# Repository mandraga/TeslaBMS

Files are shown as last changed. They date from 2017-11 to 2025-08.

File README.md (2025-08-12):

## Adaptation to Teensy 4.

This fork branches to adapt to the Teensy 4, it needs an interface board pcb or a carrier board redesign.
See the VW BMS fork or the pull request at the original repo for adapter PCB in Kicad format.

# TeslaBMS

Based off work done by Collin Kidder

Designed to work with my own board design and a Teensy 3.2

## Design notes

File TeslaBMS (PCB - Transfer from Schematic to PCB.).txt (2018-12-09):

Transfer from Schematic to PCB.
-------------------------------

Report Written:     Wednesday, April 18, 2018
Design Path:        C:\Users\tomde\Documents\GitHub\TeslaBMS\TeslaBMS.pcb
Design Title:       
Created:            18-Apr-18 9:27:16 PM
Last Saved:         18-Apr-18 9:27:25 PM
Editing Time:       0 min
Units:              thou (precision 0)

Net class "default" was not defined, but has been created. Please check the values in the PCB design.
Could not load component "R-78XX" package "R-78XX" into target design.
Could not add "U1" component "R-78XX" package "R-78XX" to target design.
Could not load component "MCP2510-I/SO" package "SOIC127P1034X264-18N" into target design.
Could not add "U$2" component "MCP2510-I/SO" package "SOIC127P1034X264-18N" to target design.
Could not load component "PCA82C250T/N4,112" package "SOIC127P600X175-8N" into target design.
Could not add "U2" component "PCA82C250T/N4,112" package "SOIC127P600X175-8N" to target design.
Could not load component "CRYSTALSM49" package "SM49" into target design.
Could not add "Q1" component "CRYSTALSM49" package "SM49" to target design.
PCB component "R1" does not have a pad numbered .
Could not load component "BTS5440G" package "PG-DSO-28" into target design.
Could not add "IC2" component "BTS5440G" package "PG-DSO-28" to target design.
Could not load component "22-27-2041-04" package "6410-04" into target design.
Could not add "J2" component "22-27-2041-04" package "6410-04" to target design.
Could not add "J3" component "22-27-2041-04" package "6410-04" to target design.
PCB component "C11" does not have a pad numbered .
PCB component "C14" does not have a pad numbered .
PCB component "C17" does not have a pad numbered .
PCB component "R4" does not have a pad numbered .
Could not load component "FDD4141TO252" package "TO252" into target design.
Could not add "Q3" component "FDD4141TO252" package "TO252" to target design.
Could not load component "NPN-TRANSISTOR_SOT23" package "SOT23" into target design.
Could not add "Q4" component "NPN-TRANSISTOR_SOT23" package "SOT23" to target design.
Could not load component "TEENSY_3.1_DIL" package "TEENSY3-DIL" into target design.
Could not add "U$4" component "TEENSY_3.1_DIL" package "TEENSY3-DIL" to target design.
PCB component "R6" does not have a pad numbered .
Could not load component "ILD205" package "SOIC08" into target design.
Could not add "OK2" component "ILD205" package "SOIC08" to target design.
PCB component "R5" does not have a pad numbered .
PCB component "R7" does not have a pad numbered .
PCB component "R8" does not have a pad numbered .
PCB component "R9" does not have a pad numbered .
Could not load component "5566-8" package "5566-8" into target design.
Could not add "X1" component "5566-8" package "5566-8" to target design.
PCB component "R2" does not have a pad numbered .
PCB component "R3" does not have a pad numbered .
PCB component "R10" does not have a pad numbered .
PCB component "R11" does not have a pad numbered .
PCB component "R12" does not have a pad numbered .
PCB component "R13" does not have a pad numbered .
Could not load component "MOSFET-NGDS_TO220V" package "TO220V" into target design.
Could not add "Q2" component "MOSFET-NGDS_TO220V" package "TO220V" to target design.
Could not add "Q5" component "MOSFET-NGDS_TO220V" package "TO220V" to target design.

End Of Report.

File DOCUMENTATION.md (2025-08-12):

Install the autowp MCP2515 library from the library menu.

Install the ADC library from https://github.com/pedvide/ADC from a zip file.

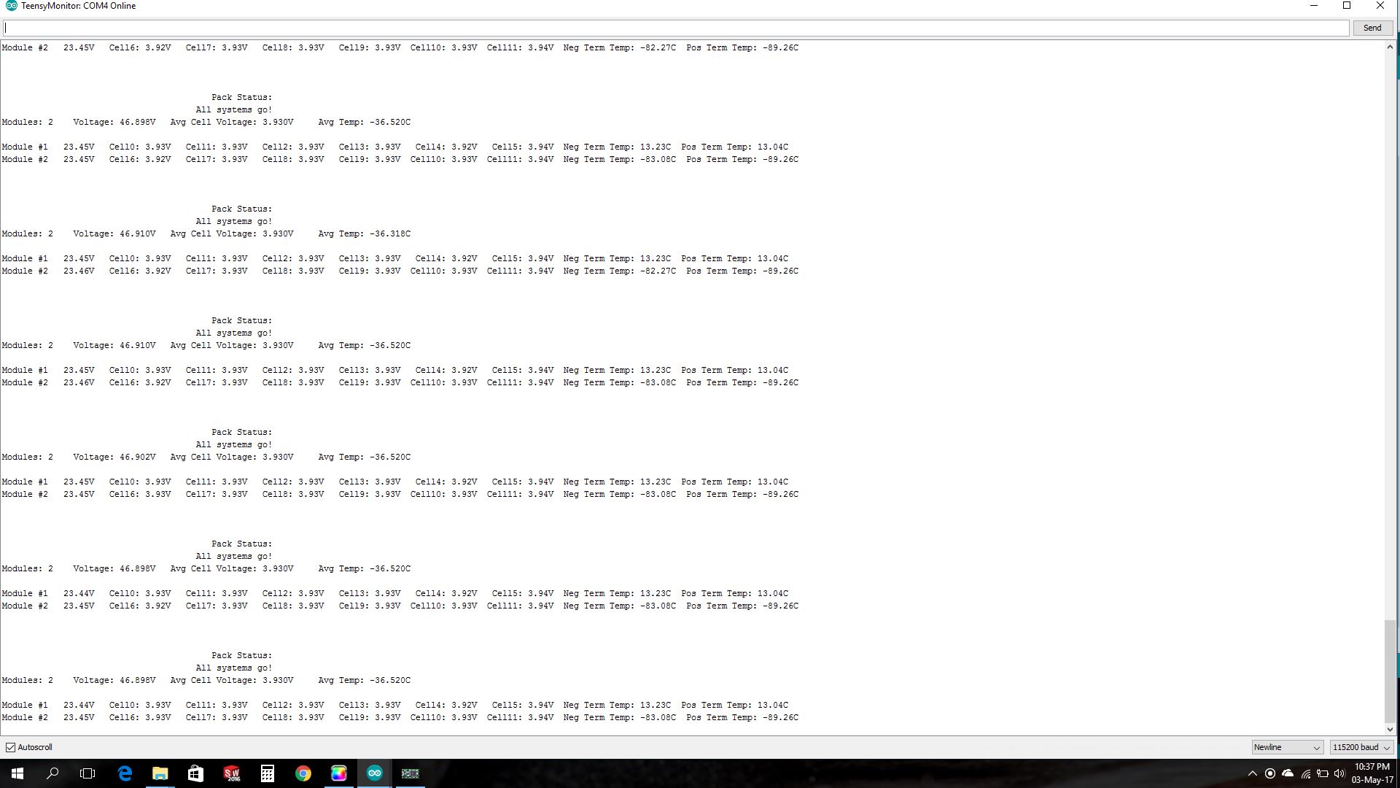
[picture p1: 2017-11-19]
running.JPG

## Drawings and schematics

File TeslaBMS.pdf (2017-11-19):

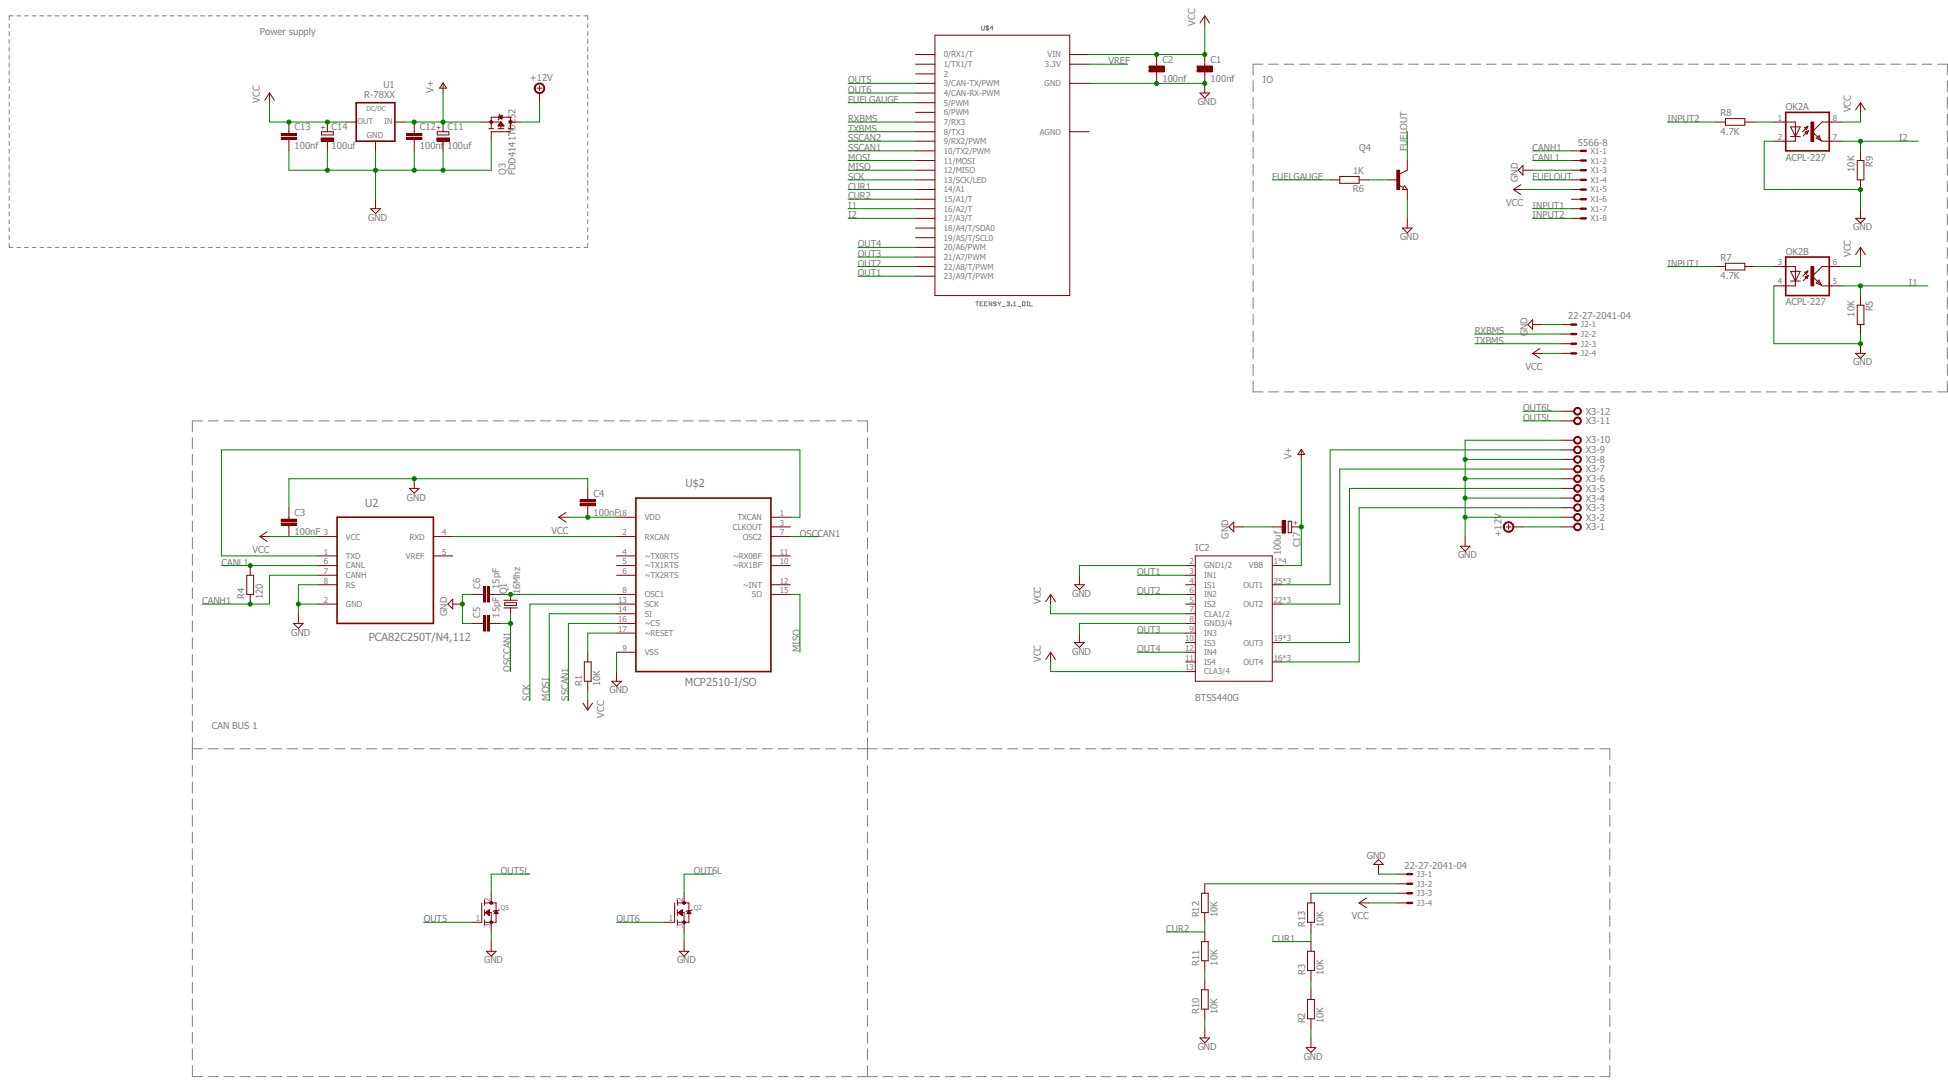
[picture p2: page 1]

~RESET 17

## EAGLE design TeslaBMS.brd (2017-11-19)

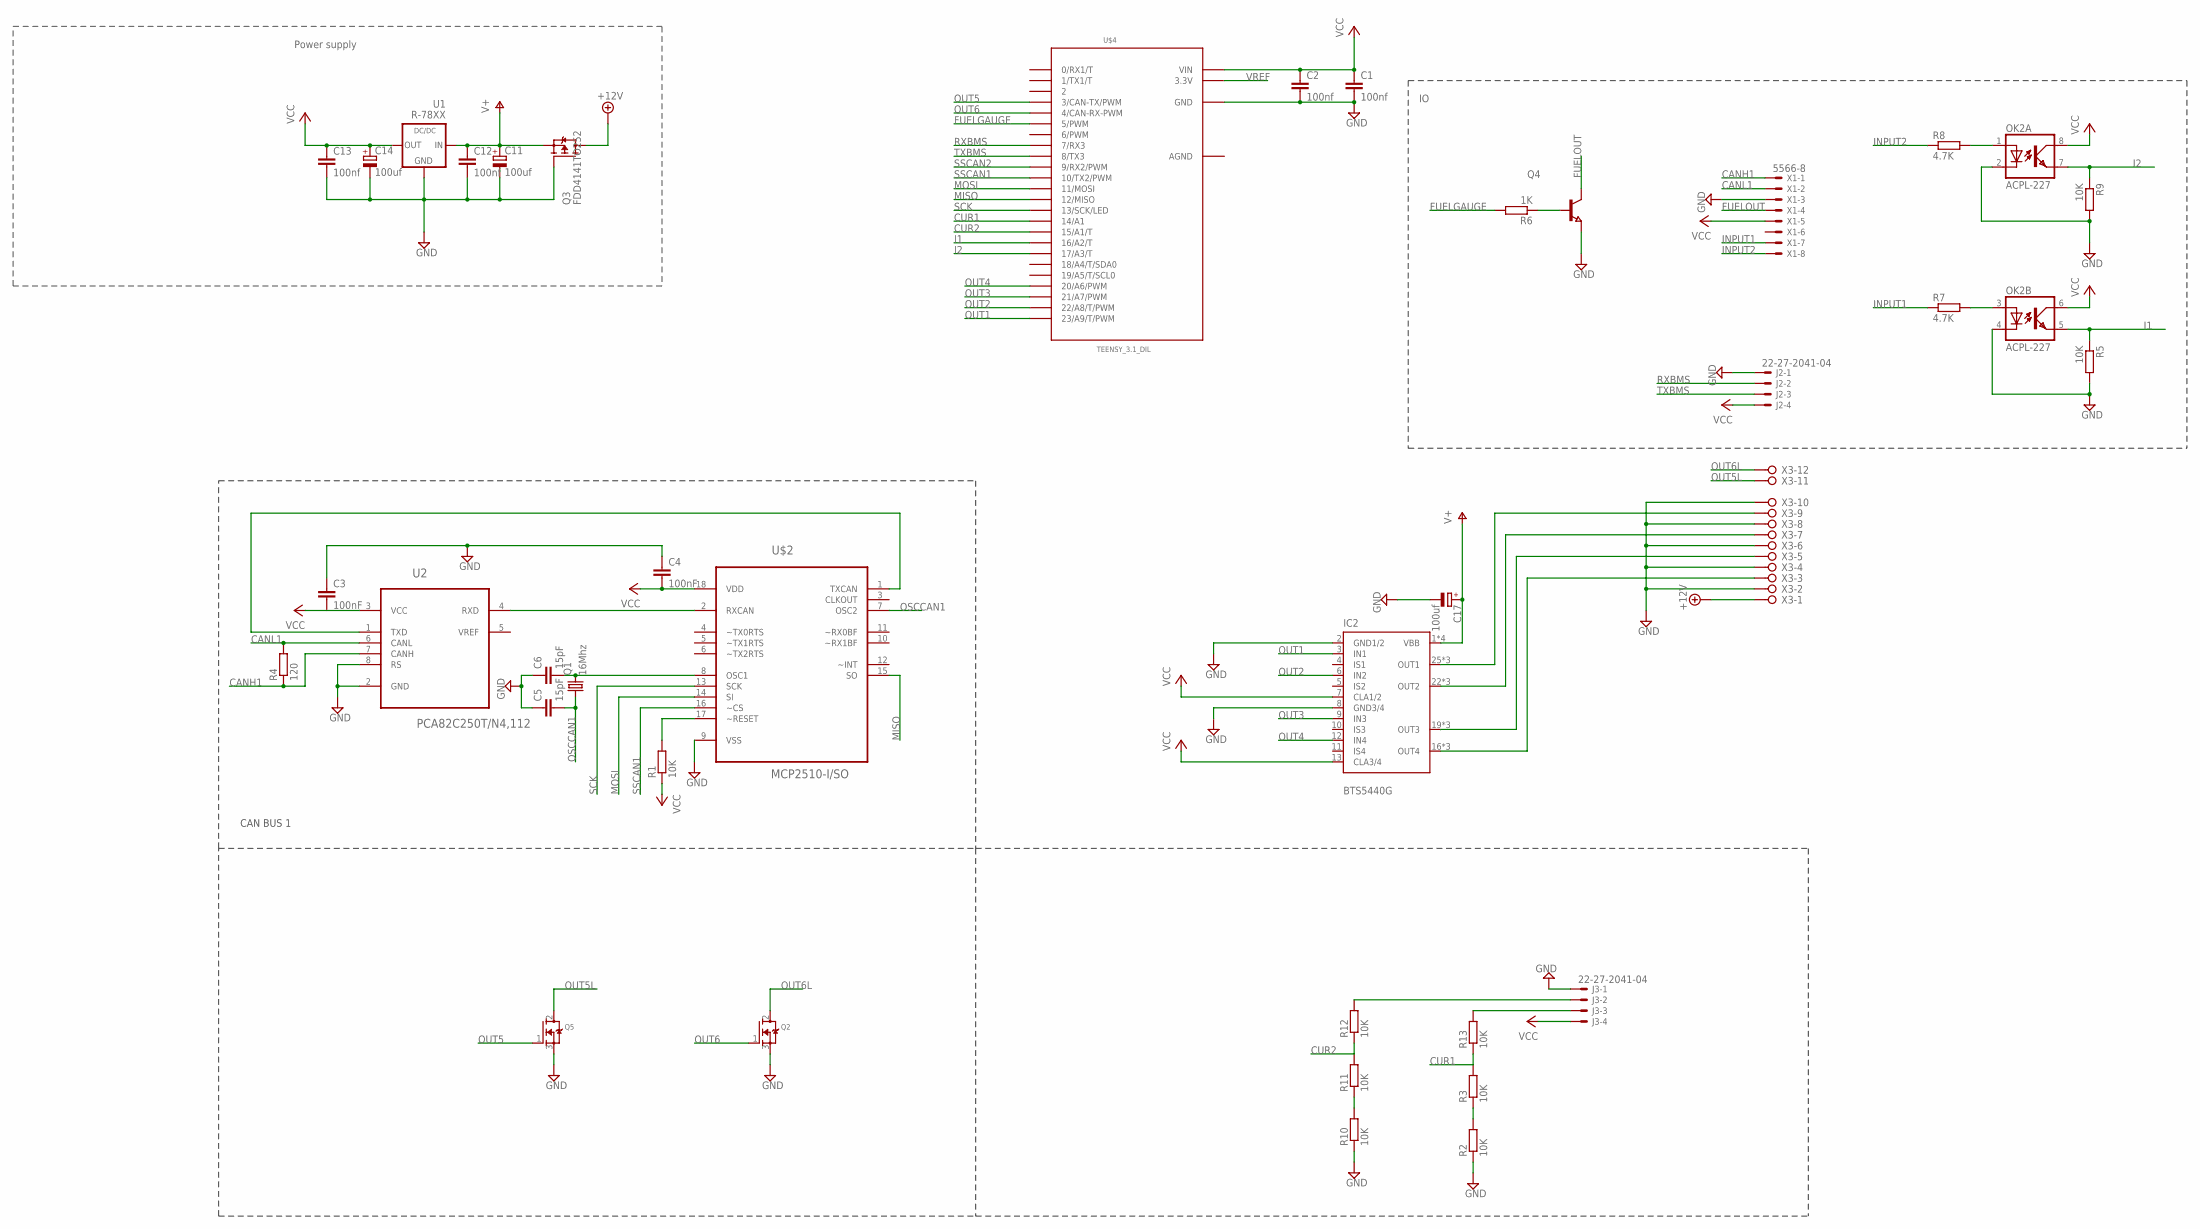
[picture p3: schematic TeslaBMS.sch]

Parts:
C1, C2, C12, C13: 100nf; C0805
C3, C4: 100nF; C0805
C5, C6: 15pF; C0805
C11, C14, C17: 100uf; 153CLV-0810
IC2: BTS5440G; PG-DSO-28
J2, J3: 22-27-2041-04; 6410-04
OK2: ACPL-227; SOIC08
Q1: 16Mhz; SM49
Q2, Q5: MOSFET-NGDS_TO220V; TO220V
Q3: FDD4141TO252; TO252
Q4: NPN-TRANSISTOR_SOT23; SOT23
R1, R2, R3, R5, R9, R10, R11, R12, R13: 10K; R0805
R4: 120; R0805
R6: 1K; R0805
R7, R8: 4.7K; R0805
U1: R-78XX
U2: PCA82C250T/N4,112; SOIC127P600X175-8N
U$2: MCP2510-I/SO; SOIC127P1034X264-18N
U$4: TEENSY_3.1_DIL; TEENSY3-DIL
X1: 5566-8
X3: W237-12P

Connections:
+12V: Q3.3 (D), X3.1
AGND: U$4.AGND
CANH1: R4.1, U2.7 (CANH), X1.1
CANH2: J3.3, R13.2
CANL1: R4.2, U2.6 (CANL), X1.2
CANL2: J3.2, R12.2
CUR1: R3.2, R13.1, U$4.14/A0 (14/A1)
CUR2: R11.2, R12.1, U$4.15/A1 (15/A1/T)
FUELGAUGE: R6.2, U$4.5 (5/PWM)
FUELOUT: Q4.3 (C), X1.4
GND: C1.2, C2.2, C3.1, C4.1, C5.1, C6.1, C11.-, C12.2, C13.2, C14.-, C17.-, IC2.2 (GND1/2), IC2.8 (GND3/4), J2.1, J3.1, OK2.2 (C), OK2.4 (C), Q2.3 (S), Q3.1 (G), Q4.2 (E), Q5.3 (S), R2.1, R5.2, R9.2, R10.1, U1.2 (GND), U2.2 (GND), U2.8 (RS), U$2.9 (VSS), U$4.GND, X1.3, X3.2, X3.4, X3.6, X3.8, X3.10
I1: OK2.5 (EMIT), R5.1, U$4.16/A2 (16/A2/T)
I2: OK2.7 (EMIT), R9.1, U$4.17/A3 (17/A3/T)
INPUT1: R7.1, X1.7
INPUT2: R8.1, X1.8
MISO: U$2.15 (SO), U$4.12 (12/MISO)
MOSI: U$2.14 (SI), U$4.11 (11/MOSI)
unnamed: U2.4 (RXD), U$2.2 (RXCAN)
unnamed: U2.1 (TXD), U$2.1 (TXCAN)
unnamed: R1.2, U$2.17 (~RESET)
unnamed: R2.2, R3.1
unnamed: R10.2, R11.1
unnamed: C6.2, Q1.2, U$2.8 (OSC1)
unnamed: Q4.1 (B), R6.1
unnamed: OK2.3 (A), R7.2
unnamed: OK2.1 (A), R8.2
unnamed: IC2.22 (OUT2), IC2.23 (OUT2), IC2.24 (OUT2), X3.7
unnamed: IC2.19 (OUT3), IC2.20 (OUT3), IC2.21 (OUT3), X3.5
unnamed: IC2.16 (OUT4), IC2.17 (OUT4), IC2.18 (OUT4), X3.3
unnamed: IC2.25 (OUT1), IC2.26 (OUT1), IC2.27 (OUT1), X3.9
OSCCAN1: C5.2, Q1.1, U$2.7 (OSC2)
OUT1: IC2.3 (IN1), U$4.23/A9 (23/A9/T/PWM)
OUT2: IC2.6 (IN2), U$4.22/A8 (22/A8/T/PWM)
OUT3: IC2.9 (IN3), U$4.21/A7 (21/A7/PWM)
OUT4: IC2.12 (IN4), U$4.20/A6 (20/A6/PWM)
OUT5: Q5.1 (G), U$4.3 (3/CAN-TX/PWM)
OUT5L: Q5.2 (D), X3.11
OUT6: Q2.1 (G), U$4.4 (4/CAN-RX-PWM)
OUT6L: Q2.2 (D), X3.12
RXBMS: J2.2, U$4.7 (7/RX3)
SCK: U$2.13 (SCK), U$4.13 (13/SCK/LED)
SSCAN1: U$2.16 (~CS), U$4.10 (10/TX2/PWM)
SSCAN2: U$4.9 (9/RX2/PWM)
TXBMS: J2.3, U$4.8 (8/TX3)
V+: C11.+, C12.1, C17.+, IC2.1 (VBB), IC2.14 (VBB), IC2.15 (VBB), IC2.28 (VBB), Q3.2 (S), U1.1 (IN)
VCC: C1.1, C2.1, C3.2, C4.2, C13.1, C14.+, IC2.7 (CLA1/2), IC2.13 (CLA3/4), J2.4, J3.4, OK2.6 (COL), OK2.8 (COL), R1.1, U1.3 (OUT), U2.3 (VCC), U$2.18 (VDD), U$4.VIN, X1.5
VREF: U$4.3.3V

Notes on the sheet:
Power supply
CAN BUS 1

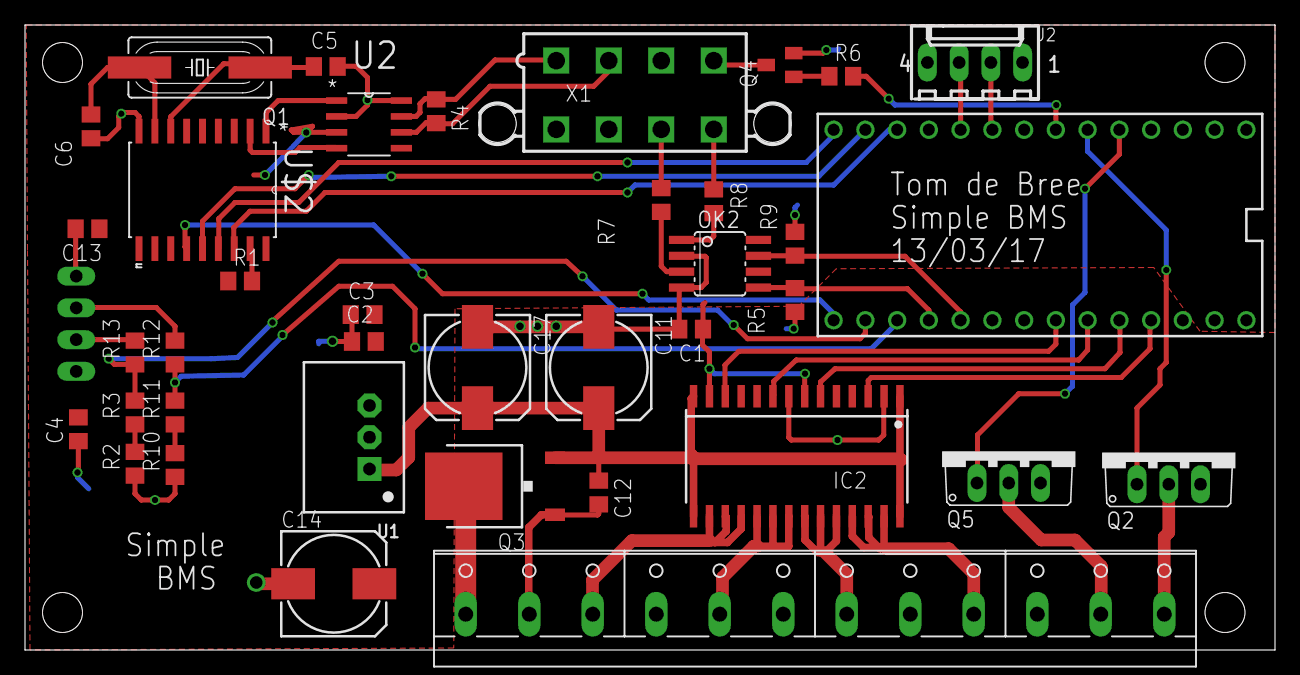
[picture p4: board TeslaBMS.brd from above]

Board: 2 copper layers, 100.0 x 50.0 mm, 39 parts (1 on the bottom side), 44 nets.

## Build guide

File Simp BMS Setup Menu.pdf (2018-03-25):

# Simp BMS Setup Menu

## Menu

Once connected to the Simp BMS via the serial port (115200 BAUD)

Send the command: s

This stops the scrolling of the diagnostics info.

And displays the following options:

c - Current Sensor Calibration

b- Battery Settings

q - exit menu

Menu structure
‘c’

Brings up the current sensor menu, this is currently only applicable for analogue sensors.

c - To calibrate sensor offset

s - To switch between Current Sensors

q - Go back to menu

‘b’

Brings up the battery calibration menu.

r - Reset AH counter

d - Display settings

e - Edit settings

q - Go back to menu

‘r’
Resets the AH counter to 0, this should only be done if the battery is almost completely empty. New revision of code will allow reset of SOC with average cell voltage.

‘d’
Display all the battery variables, run this before running ‘e’

[value] mV Over Voltage Setpoint - 1

[value] mV Under Voltage Setpoint - 2

[value] Over Temperature Setpoint - 3

[value] Under Temperature Setpoint - 4

[value] mV Balance Voltage Setpoint - 5

[value] mV Balance Voltage Hystersis - 6

[value] Ah Battery Capacity - 7

[value] A max Charge - 8

[value] A max Discharge - 9

‘e’
To change a variable displayed in ‘d’, in put ‘e’ followed by variable number then a ‘space’ new value

‘q’

Exit the setup menu and resume diagnostics display info

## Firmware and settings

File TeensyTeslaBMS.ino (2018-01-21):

#include "BMSModuleManager.h"
#include <Arduino.h>
#include "config.h"
#include "SerialConsole.h"
#include "Logger.h"
#include <ADC.h>

#include <mcp_can.h>
#include <SPI.h>

BMSModuleManager bms;
SerialConsole console;
EEPROMSettings settings;


//Simple BMS wiring//
const int ACUR1 = A0; // current 1
const int ACUR2 = A1; // current 2
const int IN1 = 16; // input 1 - high active
const int IN2 = 17; // input 2- high active
const int OUT1 = 20;// output 1 - high active
const int OUT2 = 21;// output 1 - high active
const int OUT3 = 23;// output 1 - high active
const int OUT4 = 24;// output 1 - high active
const int OUT5 = 3;// output 1 - high active
const int OUT6 = 4;// output 1 - high active
const int FUEL = 5;// Fuel gauge pwm signal
const int led = 13;

byte bmsstatus = 0;
//bms status values
#define Boot 0
#define Ready 1
#define Drive 2
#define Charge 3
#define Precharge 4
#define Error 5
//

int Discharge;

//variables for output control
int pulltime = 1000;
int contctrl, contstat = 0; //1 = out 5 high 2 = out 6 high 3 = both high
unsigned long conttimer, Pretimer = 0;
int Pretime = 5000; //precharge timer
int conthold = 50; //holding duty cycle for contactor 0-255
int Precurrent = 1000; //ma before closing main contator

int gaugelow = 255; //empty fuel gauge pwm
int gaugehigh = 70; //full fuel gauge pwm

//variables for VE driect bus comms
char* myStrings[] = {"V", "14674", "I", "0", "CE", "-1", "SOC", "800", "TTG", "-1", "Alarm", "OFF", "Relay", "OFF", "AR", "0", "BMV", "600S", "FW", "212", "H1", "-3", "H2", "-3", "H3", "0", "H4", "0", "H5", "0", "H6", "-7", "H7", "13180", "H8", "14774", "H9", "137", "H10", "0", "H11", "0", "H12", "0"};

//variables for VE can
uint16_t chargevoltage = 49100; //max charge voltage in mv
uint16_t chargecurrent = 30000; //max charge current in ma
uint16_t disvoltage = 42000; // max discharge voltage in mv
uint16_t discurrent = 30000; // max discharge current in ma
uint16_t SOH = 100; // SOH place holder

unsigned char mes[8] = {0, 0, 0, 0, 0, 0, 0, 0};
unsigned char bmsname[8] = {'S', 'I', 'M', 'P', ' ', 'B', 'M', 'S'};
unsigned char bmsmanu[8] = {'T', 'O', 'M', ' ', 'D', 'E', ' ', 'B'};

MCP_CAN CAN(10); //set CS pin for can controlelr


//variables for current calulation
int value;
int invertcur = 0;
uint16_t offset1 = 1735;
uint16_t offset2 = 1733;
int highconv = 285;
float currentact, RawCur;
float ampsecond;
unsigned long lasttime;
unsigned long looptime;
int currentsense = 14;
int sensor = 1;

//running average
const int RunningAverageCount = 16;
float RunningAverageBuffer[RunningAverageCount];
int NextRunningAverage;

//Variables for SOC calc
int SOC = 100; //State of Charge
int SOCset = 0;
uint16_t socvolt[4] = {3100, 10, 4100,90};
int CAP = 100; //battery size in Ah

//variables
int incomingByte = 0;
int x = 0;
int debug = 1;
int debugCur = 0;
int menuload = 0;


ADC *adc = new ADC(); // adc object

void loadSettings()
{
  Logger::console("Resetting to factory defaults");
  settings.version = 0;
  settings.checksum = 0;
  settings.canSpeed = 500000;
  settings.batteryID = 0x01; //in the future should be 0xFF to force it to ask for an address
  settings.OverVSetpoint = 4.1f;
  settings.UnderVSetpoint = 3.0f;
  settings.OverTSetpoint = 65.0f;
  settings.UnderTSetpoint = -10.0f;
  settings.balanceVoltage = 3.9f;
  settings.balanceHyst = 0.04f;
  settings.logLevel = 2;
}


uint32_t lastUpdate;


void setup()
{
  delay(4000);  //just for easy debugging. It takes a few seconds for USB to come up properly on most OS's
  pinMode(ACUR1, INPUT);
  pinMode(ACUR2, INPUT);
  pinMode(IN1, INPUT);
  pinMode(IN2, INPUT);
  pinMode(OUT1, OUTPUT); // drive contactor
  pinMode(OUT2, OUTPUT); // precharge
  pinMode(OUT3, OUTPUT); // charge relay
  pinMode(OUT4, OUTPUT); // Negative contactor
  pinMode(OUT5, OUTPUT); // pwm driver output
  pinMode(OUT6, OUTPUT); // pwm driver output
  pinMode(FUEL, OUTPUT);
  pinMode(led, OUTPUT);

  if (CAN.begin(MCP_ANY, CAN_250KBPS, MCP_16MHZ) == CAN_OK) Serial.println("MCP2515 Initialized Successfully!");
  else Serial.println("Error Initializing MCP2515...");

  CAN.setMode(MCP_NORMAL);

  adc->setAveraging(16); // set number of averages
  adc->setResolution(16); // set bits of resolution
  adc->setConversionSpeed(ADC_CONVERSION_SPEED::MED_SPEED);
  adc->setSamplingSpeed(ADC_SAMPLING_SPEED::MED_SPEED);
  adc->startContinuous(ACUR1, ADC_0);


  SERIALCONSOLE.begin(115200);
  SERIALCONSOLE.println("Starting up!");
  SERIALBMS.begin(612500); //Tesla serial bus
  //VE.begin(19200); //Victron VE direct bus
#if defined (__arm__) && defined (__SAM3X8E__)
  serialSpecialInit(USART0, 612500); //required for Due based boards as the stock core files don't support 612500 baud.
#endif

  SERIALCONSOLE.println("Started serial interface to BMS.");



  loadSettings();

  bms.renumberBoardIDs();

  Logger::setLoglevel(Logger::Off); //Debug = 0, Info = 1, Warn = 2, Error = 3, Off = 4

  lastUpdate = 0;

  //bms.clearFaults();
  bms.findBoards();
  digitalWrite(led, HIGH);
}

void loop()
{
  //console.loop();

  if (SERIALCONSOLE.available() > 0)
  {
    menu();
  }

  contcon();

  switch (bmsstatus)
  {
    case (Boot):
      Discharge = 0;
      if (bms.getLowVoltage() < settings.UnderVSetpoint);
      {
        bmsstatus = Error;
      }

      bmsstatus = Ready;
      break;

    case (Ready):
      Discharge = 0;
      if (bms.getHighVoltage() > settings.balanceVoltage);
      {
        bms.balanceCells();
      }
      if (bms.getLowVoltage() < settings.UnderVSetpoint);
      {
        //bmsstatus = Error;
      }
      if (digitalRead(IN2) == HIGH && (settings.balanceVoltage + settings.balanceHyst) > bms.getHighVoltage()) //detect AC present for charging and check not balancing
      {
        bmsstatus = Charge;
      }
      if (digitalRead(IN1) == HIGH) //detect Key ON
      {
        bmsstatus = Precharge;
        Pretimer = millis();
      }

      break;

    case (Precharge):
      Discharge = 0;
      Prechargecon();
      break;


    case (Drive):
      Discharge = 1;
      if (bms.getHighVoltage() > settings.OverVSetpoint);
      {
        //bmsstatus = Error;
      }
      if (bms.getLowVoltage() < settings.UnderVSetpoint);
      {
        //bmsstatus = Error;
      }
      if (digitalRead(IN1) == LOW)//Key OFF
      {
        digitalWrite(OUT4, LOW);
        digitalWrite(OUT1, LOW);

        contctrl = 0; //turn off out 5 and 6
        bmsstatus = Ready;
      }

      break;

    case (Charge):
      Discharge = 0;
      digitalWrite(OUT3, HIGH);//enable charger
      if (bms.getHighVoltage() > settings.balanceVoltage);
      {
        bms.balanceCells();
      }
      if (bms.getHighVoltage() > settings.OverVSetpoint);
      {
        digitalWrite(OUT3, LOW);//turn off charger
        bmsstatus = Ready;
      }
      if (digitalRead(IN2) == LOW)//detect AC not present for charging
      {
        digitalWrite(OUT3, LOW);//turn off charger
        bmsstatus = Ready;
      }
      break;

    case (Error):
      Discharge = 0;

      if (digitalRead(IN2) == HIGH) //detect AC present for charging
      {
        bmsstatus = Charge;
      }
      break;
  }

  getcurrent();

  if (millis() - looptime > 500)
  {

    looptime = millis();
    bms.getAllVoltTemp();
    if (debug != 0)
    {
      printbmsstat();
      bms.printPackDetails();
    }
    updateSOC();
    //BMVmessage();
    //gaugeupdate();
    VEcan();
  }
}

void gaugeupdate()
{
  analogWrite(FUEL, map(SOC, 0, 100, gaugelow, gaugehigh));
  if (debug != 0)
  {
    SERIALCONSOLE.println("  ");
    SERIALCONSOLE.print("fuel pwm : ");
    SERIALCONSOLE.print(map(SOC, 0, 100, gaugelow, gaugehigh));
    SERIALCONSOLE.println("  ");
  }
}

void printbmsstat()
{
  SERIALCONSOLE.println();
  SERIALCONSOLE.println();
  SERIALCONSOLE.println();
  SERIALCONSOLE.print("BMS Status : ");
  SERIALCONSOLE.print(bmsstatus);
  switch (bmsstatus)
  {
    case (Boot):
      SERIALCONSOLE.print(" Boot ");
      break;

    case (Ready):
      SERIALCONSOLE.print(" Ready ");
      break;

    case (Precharge):
      SERIALCONSOLE.print(" Precharge ");
      break;

    case (Drive):
      SERIALCONSOLE.print(" Drive ");
      break;

    case (Charge):
      SERIALCONSOLE.print(" Charge ");
      break;

    case (Error):
      SERIALCONSOLE.print(" Error ");
      break;
  }
  SERIALCONSOLE.print("  ");
  if (digitalRead(IN2) == HIGH)
  {
    SERIALCONSOLE.print("| AC Present |");
  }
  if (digitalRead(IN1) == HIGH)
  {
    SERIALCONSOLE.print("| Key ON |");
  }
}


void getcurrent()
{
  if (currentact < 19000 && currentact > -19000)
  {
    sensor = 1;
    adc->startContinuous(ACUR1, ADC_0);
  }
  else
  {
    sensor = 2;
    adc->startContinuous(ACUR2, ADC_0);
  }

  if (sensor == 1)
  {
    if (debugCur != 0)
    {
      SERIALCONSOLE.print("Low Range: ");
      SERIALCONSOLE.print("Value ADC0: ");
    }
    value = (uint16_t)adc->analogReadContinuous(ADC_0); // the unsigned is necessary for 16 bits, otherwise values larger than 3.3/2 V are negative!
    if (debugCur != 0)
    {
      SERIALCONSOLE.print(value * 3.3 / adc->getMaxValue(ADC_0), 5);
      SERIALCONSOLE.print("  ");
    }
    RawCur = (float(value * 3300 / adc->getMaxValue(ADC_0)) - offset1) * 15.7;
    if (debugCur != 0)
    {
      SERIALCONSOLE.print("  ");
      SERIALCONSOLE.print(RawCur);
      SERIALCONSOLE.print("mA");
      SERIALCONSOLE.print("  ");
    }
  }
  else
  {
    if (debugCur != 0)
    {
      SERIALCONSOLE.print("High Range: ");
      SERIALCONSOLE.print("Value ADC0: ");
    }
    value = (uint16_t)adc->analogReadContinuous(ADC_0); // the unsigned is necessary for 16 bits, otherwise values larger than 3.3/2 V are negative!
    if (debugCur != 0)
    {
      SERIALCONSOLE.print(value * 3.3 / adc->getMaxValue(ADC_0), 5);
      SERIALCONSOLE.print("  ");
    }
    RawCur = (float(value * 3300 / adc->getMaxValue(ADC_0)) - offset2) * highconv;
    if (debugCur != 0)
    {
      SERIALCONSOLE.print("  ");
      SERIALCONSOLE.print(RawCur);
      SERIALCONSOLE.print("mA");
      SERIALCONSOLE.print("  ");
    }
  }

  if (invertcur == 1)
  {
    RawCur = RawCur * -1;
  }
  RunningAverageBuffer[NextRunningAverage++] = RawCur;
  if (NextRunningAverage >= RunningAverageCount)
  {
    NextRunningAverage = 0;
  }
  float RunningAverageCur = 0;
  for (int i = 0; i < RunningAverageCount; ++i)
  {
    RunningAverageCur += RunningAverageBuffer[i];
  }
  RunningAverageCur /= RunningAverageCount;

  currentact = RunningAverageCur;

  if (sensor == 1)
  {
    if (currentact > 500 || currentact < -500 )
    {
      ampsecond = ampsecond + ((currentact * (millis() - lasttime) / 1000) / 1000);
      lasttime = millis();
    }
    else
    {
      lasttime = millis();
    }
  }
  if (sensor == 2)
  {
    if (currentact > 180000 || currentact < -18000 )
    {
      ampsecond = ampsecond + ((currentact * (millis() - lasttime) / 1000) / 1000);
      lasttime = millis();
    }
    else
    {
      lasttime = millis();
    }
  }

}

void updateSOC()
{
  if (SOCset == 0)
  {
    SOC = map(uint16_t(bms.getAvgCellVolt()*1000),socvolt[0],socvolt[2],socvolt[1],socvolt[3]);
    SERIALCONSOLE.print("  ");
    SERIALCONSOLE.print(SOC);
    SERIALCONSOLE.print("  ");
    ampsecond = (SOC*CAP*10)/ 0.27777777777778 ;
    SOCset = 1;
  }
  SOC = ((ampsecond * 0.27777777777778)/(CAP * 1000)) * 100;

  if (debug != 0)
  {
    if (sensor == 1)
    {
      SERIALCONSOLE.print("Low Range ");
    }
    else
    {
      SERIALCONSOLE.print("High Range");
    }
    SERIALCONSOLE.print("  ");
    SERIALCONSOLE.print(currentact);
    SERIALCONSOLE.print("mA");
    SERIALCONSOLE.print("  ");
    SERIALCONSOLE.print(SOC);
    SERIALCONSOLE.print("% SOC ");
    SERIALCONSOLE.print(ampsecond * 0.27777777777778, 2);
    SERIALCONSOLE.println ("mAh");

  }
}

void Prechargecon()
{
  if (digitalRead(IN1) == HIGH) //detect Key ON
  {
    digitalWrite(OUT4, HIGH);//Negative Contactor Close
    contctrl = 2;
    if (Pretimer + Pretime > millis() || currentact > Precurrent)
    {
      digitalWrite(OUT2, HIGH);//precharge
    }
    else //close main contactor
    {
      digitalWrite(OUT1, HIGH);//Positive Contactor Close
      contctrl = 3;
      bmsstatus = Drive;
      digitalWrite(OUT2, LOW);
    }
  }
  else
  {
    bmsstatus = Ready;
    contctrl = 0;
  }
}

void contcon()
{
  if (contctrl != contstat) //check for contactor request change
  {
    if ((contctrl & 1) == 0)
    {
      analogWrite(OUT5, 0);
      contstat = contstat & 254;
    }
    if ((contctrl & 2) == 0)
    {
      analogWrite(OUT6, 0);
      contstat = contstat & 253;
    }

    if ((contctrl & 1) == 1)
    {
      if (conttimer == 0)
      {
        analogWrite(OUT5, 255);
        conttimer = millis() + pulltime ;
      }
      if (conttimer < millis())
      {
        analogWrite(OUT5, conthold);
        contstat = contstat | 1;
        conttimer = 0;
      }
    }

    if ((contctrl & 2) == 2)
    {
      if (conttimer == 0)
      {
        analogWrite(OUT6, 255);
        conttimer = millis() + pulltime ;
      }
      if (conttimer < millis())
      {
        analogWrite(OUT6, conthold);
        contstat = contstat | 2;
        conttimer = 0;
      }
    }
    /*
       SERIALCONSOLE.print(conttimer);
       SERIALCONSOLE.print("  ");
       SERIALCONSOLE.print(contctrl);
       SERIALCONSOLE.print("  ");
       SERIALCONSOLE.print(contstat);
       SERIALCONSOLE.println("  ");
    */

  }
}

void calcur()
{
  adc->startContinuous(ACUR1, ADC_0);
  sensor = 1;
  SERIALCONSOLE.print(" Calibrating Current Offset ::::: ");
  while (x < 20)
  {
    offset1 = offset1 + ((uint16_t)adc->analogReadContinuous(ADC_0) * 3300 / adc->getMaxValue(ADC_0));
    SERIALCONSOLE.print(".");
    delay(100);
    x++;
  }
  offset1 = offset1 / 21;
  SERIALCONSOLE.print(offset1);
  SERIALCONSOLE.print(" current offset 1 calibrated ");
  SERIALCONSOLE.println("  ");
  x = 0;
  adc->startContinuous(ACUR2, ADC_0);
  sensor = 2;
  SERIALCONSOLE.print(" Calibrating Current Offset ::::: ");
  while (x < 20)
  {
    offset2 = offset2 + ((uint16_t)adc->analogReadContinuous(ADC_0) * 3300 / adc->getMaxValue(ADC_0));
    SERIALCONSOLE.print(".");
    delay(100);
    x++;
  }
  offset2 = offset2 / 21;
  SERIALCONSOLE.print(offset2);
  SERIALCONSOLE.print(" current offset 2 calibrated ");
  SERIALCONSOLE.println("  ");
}

void VEcan() //communication with Victron system over CAN
{
  mes[0] = lowByte(chargevoltage / 100);
  mes[1] = highByte(chargevoltage / 100);
  mes[2] = lowByte(chargecurrent / 100);
  mes[3] = highByte(chargecurrent / 100);
  mes[4] = lowByte(discurrent / 100);
  mes[5] = highByte(discurrent / 100);
  mes[6] = lowByte(disvoltage / 100);
  mes[7] = highByte(disvoltage / 100);

  CAN.sendMsgBuf(0x351, 0, 8, mes);

  mes[0] = lowByte(SOC);
  mes[1] = highByte(SOC);
  mes[2] = lowByte(SOH);
  mes[3] = highByte(SOH);
  mes[4] = lowByte(SOC * 10);
  mes[5] = highByte(SOC * 10);
  mes[6] = 0;
  mes[7] = 0;

  CAN.sendMsgBuf(0x355, 0, 8, mes);

  mes[0] = lowByte(uint16_t(bms.getPackVoltage() * 100));
  mes[1] = highByte(uint16_t(bms.getPackVoltage() * 100));
  mes[2] = lowByte(long(currentact / 100));
  mes[3] = highByte(long(currentact / 100));
  mes[4] = lowByte(uint16_t(bms.getAvgTemperature() * 10));
  mes[5] = highByte(uint16_t(bms.getAvgTemperature() * 10));

  CAN.sendMsgBuf(0x356, 0, 8, mes);

  mes[0] = 0;
  mes[1] = 0;
  mes[2] = 0;
  mes[3] = 0;
  mes[4] = 0;
  mes[5] = 0;
  mes[6] = 0;
  mes[7] = 0;

  CAN.sendMsgBuf(0x35A, 0, 8, mes);
  delay(5);
  CAN.sendMsgBuf(0x370, 0, 8, bmsname);
  delay(5);
  CAN.sendMsgBuf(0x35E, 0, 8, bmsmanu);

}

void BMVmessage()//communication with the Victron Color Control System over VEdirect
{
  lasttime = millis();
  x = 0;
  VE.write(13);
  VE.write(10);
  VE.write(myStrings[0]);
  VE.write(9);
  VE.print(bms.getPackVoltage() * 1000, 0);
  VE.write(13);
  VE.write(10);
  VE.write(myStrings[2]);
  VE.write(9);
  VE.print(currentact);
  VE.write(13);
  VE.write(10);
  VE.write(myStrings[4]);
  VE.write(9);
  VE.print(ampsecond * 0.27777777777778, 0); //consumed ah
  VE.write(13);
  VE.write(10);
  VE.write(myStrings[6]);
  VE.write(9);
  VE.print(SOC * 10); //SOC
  x = 8;
  while (x < 20)
  {
    VE.write(13);
    VE.write(10);
    VE.write(myStrings[x]);
    x ++;
    VE.write(9);
    VE.write(myStrings[x]);
    x ++;
  }
  VE.write(13);
  VE.write(10);
  VE.write("Checksum");
  VE.write(9);
  VE.write(0x50); //0x59
  delay(10);

  while (x < 44)
  {
    VE.write(13);
    VE.write(10);
    VE.write(myStrings[x]);
    x ++;
    VE.write(9);
    VE.write(myStrings[x]);
    x ++;
  }
  /*
    VE.write(13);
    VE.write(10);
    VE.write(myStrings[32]);
    VE.write(9);
    VE.print(bms.getLowVoltage()*1000,0);
    VE.write(13);
    VE.write(10);
    VE.write(myStrings[34]);
    VE.write(9);
    VE.print(bms.getHighVoltage()*1000,0);
    x=36;

    while(x < 43)
    {
     VE.write(13);
     VE.write(10);
     VE.write(myStrings[x]);
     x ++;
     VE.write(9);
     VE.write(myStrings[x]);
     x ++;
    }
  */
  VE.write(13);
  VE.write(10);
  VE.write("Checksum");
  VE.write(9);
  VE.write(231);
}
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

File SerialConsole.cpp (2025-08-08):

/*
 * SerialConsole.cpp
 *
 Copyright (c) 2017 EVTV / Collin Kidder

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
 */
#include "SerialConsole.h"
#include "Logger.h"
#include "BMSModuleManager.h"

template<class T> inline Print &operator <<(Print &obj, T arg) { obj.print(arg); return obj; } //Lets us stream SerialUSB

extern BMSModuleManager bms;

bool printPrettyDisplay;
uint32_t prettyCounter;
int whichDisplay;

SerialConsole::SerialConsole() {
    init();
}

void SerialConsole::init() {
    //State variables for serial console
    ptrBuffer = 0;
    state = STATE_ROOT_MENU;
    loopcount=0;
    cancel=false;
    printPrettyDisplay = false;
    prettyCounter = 0;
    whichDisplay = 0;
}

void SerialConsole::loop() {  
    if (SERIALCONSOLE.available()) {
        serialEvent();
    }
    if (printPrettyDisplay && (millis() > (prettyCounter + 3000)))
    {
        prettyCounter = millis();
        if (whichDisplay == 0) bms.printPackSummary();
        if (whichDisplay == 1) bms.printPackDetails();
    }
}
              
void SerialConsole::printMenu() {   
    Logger::console("\n*************SYSTEM MENU *****************");
    Logger::console("Enable line endings of some sort (LF, CR, CRLF)");
    Logger::console("Most commands case sensitive\n");
    Logger::console("GENERAL SYSTEM CONFIGURATION\n");
    Logger::console("   h = help (displays this message)");
    Logger::console("   S = Sleep all boards");
    Logger::console("   W = Wake up all boards");
    Logger::console("   C = Clear all board faults");
    Logger::console("   F = Find all connected boards");
    Logger::console("   R = Renumber connected boards in sequence");
    Logger::console("   B = Attempt balancing for 5 seconds");
    Logger::console("   p = Toggle output of pack summary every 3 seconds");
    Logger::console("   d = Toggle output of pack details every 3 seconds");
  
    Logger::console("   LOGLEVEL=%i - set log level (0=debug, 1=info, 2=warn, 3=error, 4=off)", Logger::getLogLevel());
/*
    float OverVSetpoint;
    float UnderVSetpoint;
    float OverTSetpoint;
    float UnderTSetpoint;
    float balanceVoltage;
    float balanceHyst;
*/
}

/*	There is a help menu (press H or h or ?)

    Commands are submitted by sending line ending (LF, CR, or both)
 */
void SerialConsole::serialEvent() {
    int incoming;
    incoming = SERIALCONSOLE.read();
    if (incoming == -1) { //false alarm....
        return;
    }

    if (incoming == 10 || incoming == 13) { //command done. Parse it.
        handleConsoleCmd();
        ptrBuffer = 0; //reset line counter once the line has been processed
    } else {
        cmdBuffer[ptrBuffer++] = (unsigned char) incoming;
        if (ptrBuffer > 79)
            ptrBuffer = 79;
    }
}

void SerialConsole::handleConsoleCmd() {

    if (state == STATE_ROOT_MENU) {
        if (ptrBuffer == 1) { //command is a single ascii character
            handleShortCmd();
        } else { //if cmd over 1 char then assume (for now) that it is a config line
            //handleConfigCmd();
        }
    }
}

void SerialConsole::handleShortCmd() 
{
    uint8_t val;

    switch (cmdBuffer[0]) 
    {
    case 'h':
    case '?':
    case 'H':
        printMenu();
        break;
    case 'S':
        Logger::console("Sleeping all connected boards");
        bms.sleepBoards();
        break;
    case 'W':
        Logger::console("Waking up all connected boards");
        bms.wakeBoards();
        break;
    case 'C':
        Logger::console("Clearing all faults");
        bms.clearFaults();
        break;
    case 'F':
        bms.findBoards();
        break;
    case 'R':
        Logger::console("Renumbering all boards.");
        bms.renumberBoardIDs();
        break;
    case 'B':
        bms.balanceCells();
        break;    
    case 'p':
        if (whichDisplay == 1 && printPrettyDisplay) whichDisplay = 0;
        else
        {
            printPrettyDisplay = !printPrettyDisplay;
            if (printPrettyDisplay)
            {
                Logger::console("Enabling pack summary display, 5 second interval");
            }
            else
            {
                Logger::console("No longer displaying pack summary.");
            }
        }
        break;
    case 'd':
        if (whichDisplay == 0 && printPrettyDisplay) whichDisplay = 1;
        else
        {
            printPrettyDisplay = !printPrettyDisplay;
            whichDisplay = 1;
            if (printPrettyDisplay)
            {
                Logger::console("Enabling pack details display, 5 second interval");
            }
            else
            {
                Logger::console("No longer displaying pack details.");
            }            
        }
        break;
    }
}

/*
    if (SERIALCONSOLE.available()) 
    {     
        char y = SERIALCONSOLE.read();
        switch (y)
        {
        case '1': //ascii 1
            renumberBoardIDs();  // force renumber and read out
            break;
        case '2': //ascii 2
            SERIALCONSOLE.println();
            findBoards();
            break;
        case '3': //activate cell balance for 5 seconds 
            SERIALCONSOLE.println();
            SERIALCONSOLE.println("Balancing");
            cellBalance();
            break;
      case '4': //clear all faults on all boards, required after Reset or FPO (first power on)
       SERIALCONSOLE.println();
       SERIALCONSOLE.println("Clearing Faults");
       clearFaults();
      break;

      case '5': //read out the status of first board
       SERIALCONSOLE.println();
       SERIALCONSOLE.println("Reading status");
       readStatus(1);
      break;

      case '6': //Read out the limit setpoints of first board
       SERIALCONSOLE.println();
       SERIALCONSOLE.println("Reading Setpoints");
       readSetpoint(1);
       SERIALCONSOLE.println(OVolt);
       SERIALCONSOLE.println(UVolt);
       SERIALCONSOLE.println(Tset);
      break; 
                
      case '0': //Send all boards into Sleep state
       Serial.println();
       Serial.println("Sleep Mode");
       sleepBoards();
      break;

      case '9'://Pull all boards out of Sleep state
       Serial.println();
       Serial.println("Wake Boards");
       wakeBoards();
      break;          
                      
        }
    }     
 */

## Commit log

2017-02-19 Update and rename TeslaBMS.ino to TeslaBMSteensy.ino
    Code now specific for Teensy 3.1, implemented changes needed from Collin's version.
2017-02-19 Update TeslaBMSteensy.ino
    Changes to organize the recognition of the adreses and assigning the 00 devices
2017-02-19 Update TeslaBMSteensy.ino
    Added a debug function to hide the uart traffic pass through
    Created line headers for converted data on serial output
2018-01-03 Update 03/01/18
    Update: SOC calc and some contactor control tweaks.
    Next: Canbus communication with Victron modules. Plus refinement of SOC calc
2018-01-21 SOC calc implementation and Canbus implementation
    Added can bus implementation, this allows broadcasting of voltage and current as well as battery limits.
    SOC calc has been improved, start point now defined by a voltage curve.
2018-01-24 Added bms method getHighCellVolt, modified the bmsstatus case statement to use this for balancing. fixed a few other bugs.
    [TeslaBMS.ino]
2018-02-16 Refining Current Sensor Usage
    Added:
    - start to implementing Can Based Current Sensor.
    - disconnected current sensor does not cause any SOC or Amphour change
    Removed:
    -None
2018-02-16 Wiped Jarrods Changes
    Fixed
    [TeslaBMS.ino]
2018-02-16 CAB300 Support
    No capable of working with the CAB300 on adress 0x3C2.
    To Toggle between analogue input or CAB300 go into Setup and then toggle sensor type.
2018-02-17 Moved UV check out of state machine
    All UV faults now result in error, moved out of statemachine to force BMS data to be read first.
    [TeslaBMS.ino]
2018-02-18 SOC reset at high end tweaking
    [TeslaBMS.ino]
2018-03-20 Added parallel strings and Ignore none connected cells
    Added parallel strings to correct voltage
    Ignore none connected cells via simple compare, voltage below 0.1V does not count for average.
    [TeslaBMS.ino]
2018-03-23 fixed charge/discharge limits and added menu for them
    fixed charge/discharge limits and added menu for them.
    Max setable currents are 3200A
    [TeslaBMS.ino]
2018-03-25 Created Alarm output structure and current scaling to temperature
    Now implemented alarm structure for Victron.
    Now allowed charge /discharge current is temperature dependant.
    Also corrected ignoring unconnected cell channels.
    [TeslaBMS.ino]
2018-03-25 More features for MB Tesla Boards
    Now added the abilty to ignore temp sensors
    Also improved ignoring unconnected cells
2018-03-26 Update with Settings for Voltage Ignoring
    Unconnected cells can cause voltage annoyance, this will create unwanted errors.
    Also turned on candebug for the current sensor.
    [TeslaBMS.ino]
2018-03-27 Output Control Fixes
    Turns out i miss numbered the outputs. Also fixed ensuring a turn-off with a loss of signal during precharge.
    [TeslaBMS.ino]
2018-04-01 Refresh canbus every few hours
    Canbus reintialize to combat controller locking up.
2018-04-13 update
    can problems trouble shooting
    [TeslaBMS.ino]
2018-12-09 Added CSV Output
    [TeslaBMS.sch, ~TeslaBMS.sch]
2025-08-08 Applies the modifications as in the VWBMS fork.
    The #include <mcp2515.h> still causes a compilaiton error. Must be
    investigated. The Teensy 4.0 has more cans so maybe it could do without
    it or we can delete this form the code if the CAN is not used.
    [SerialConsole.cpp, TeslaBMS.ino]
2025-08-12 Fixing the compilation, read DOCUMENTATION.md
    [TeslaBMS.ino]
